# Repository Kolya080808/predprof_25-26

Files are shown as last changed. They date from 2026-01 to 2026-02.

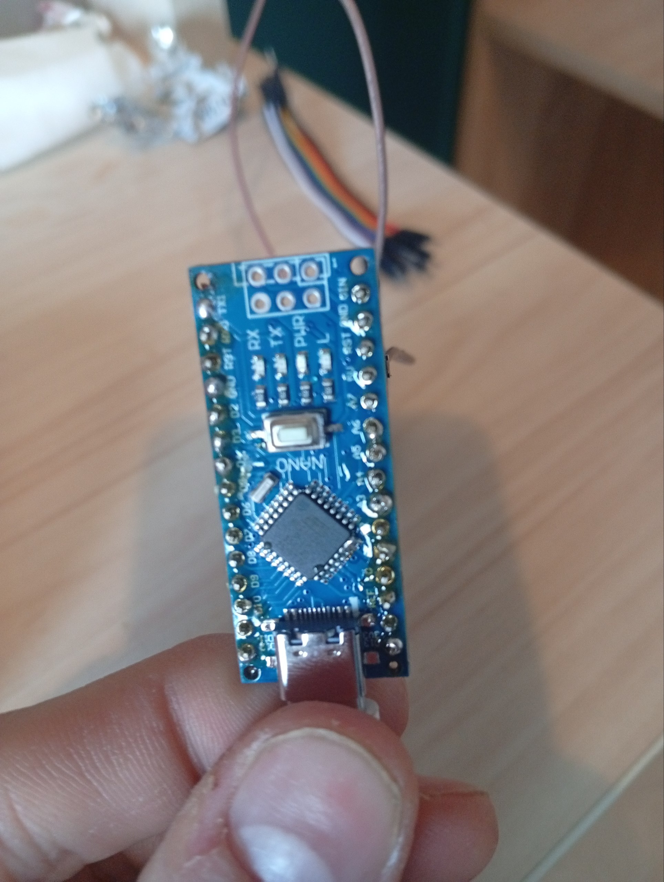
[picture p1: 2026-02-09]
ФотографииСкриншоты/Arduino Nano (transmitter).jpg

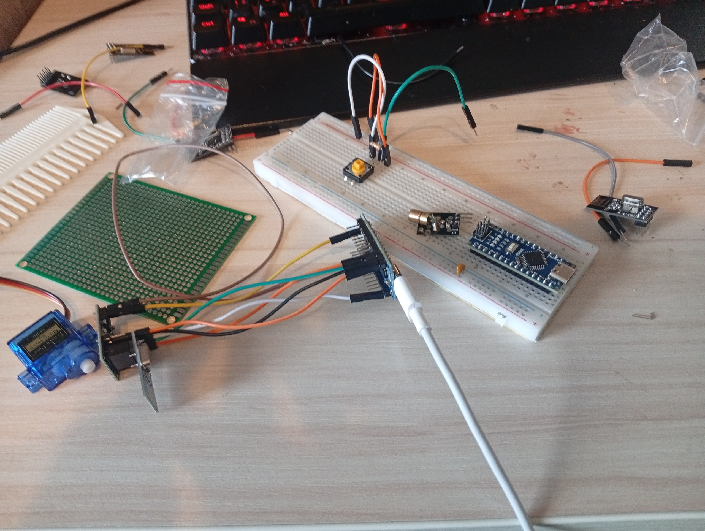
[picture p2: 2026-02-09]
ФотографииСкриншоты/Все комплектующие.jpg

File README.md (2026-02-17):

# predprof_25-26

Команда: `Шестерня и Воля`

- Код передатчика: https://github.com/Kolya080808/predprof_25-26/raw/main/%D0%9F%D1%80%D0%BE%D0%B3%D1%80%D0%B0%D0%BC%D0%BC%D0%BD%D1%8B%D0%B9%20%D0%BA%D0%BE%D0%B4/transmitter.ino
- Код приемника: https://github.com/Kolya080808/predprof_25-26/raw/main/%D0%9F%D1%80%D0%BE%D0%B3%D1%80%D0%B0%D0%BC%D0%BC%D0%BD%D1%8B%D0%B9%20%D0%BA%D0%BE%D0%B4/receiver.ino

## Схемы

- Приемник (CubeSat):



- Передатчик:



## Ссылки

- Документация: https://cloud.predprof.olimpiada.ru/index.php/s/YzEzw9Se8cmYfWE **или** https://github.com/Kolya080808/predprof_25-26/blob/main/%D1%82%D0%B7.pdf 
- Отчет: https://github.com/Kolya080808/predprof_25-26/blob/main/%D0%9E%D0%A2%D0%A7%D0%95%D0%A2%20%D0%9F%D0%A0%D0%95%D0%94%D0%9F%D0%A0%D0%9E%D0%A4.pdf
- Ролик: https://rutube.ru/video/private/c03d32e5083e5afc0b8255f1b30c7123/?p=oxefNFDY0Pq9hNCoUt_76A

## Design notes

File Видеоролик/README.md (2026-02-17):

# ССЫЛКИ НА ВИДЕОРОЛИКИ (скачивание и просмотр)

https://rutube.ru/video/private/c03d32e5083e5afc0b8255f1b30c7123/?p=oxefNFDY0Pq9hNCoUt_76A

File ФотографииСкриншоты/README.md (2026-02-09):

Фотографии разработанного устройства и составных частей, а также скриншоты моделей.

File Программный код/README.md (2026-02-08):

# ССЫЛКИ НА КОД ДЛЯ ПРИЕМНИКА И ПЕРЕДАТЧИКА
- Приемник (CubeSat): https://github.com/Kolya080808/predprof_25-26/blob/main/%D0%9F%D1%80%D0%BE%D0%B3%D1%80%D0%B0%D0%BC%D0%BC%D0%BD%D1%8B%D0%B9%20%D0%BA%D0%BE%D0%B4/receiver.ino

Алгоритм работы:

1. Задает переменные и настройки:
   - Подключает библиотеки для радио и моторов.
   - Назначает пины: 2 (лазер), 3 и 5 (сервомоторы).
   - Задает адреса для радиосвязи («CMD01» для приема, «DATA1» для отправки).
   - Создает структуру TelemetryPacket — «коробку», в которую будут упаковываться данные для отправки.

2. Создает вспомогательные функции:
   - setPosition — управляет сразу двумя моторами (наклоном и поворотом).
   - sendTelemetry — упаковывает текущие углы и режим в пакет и отправляет его по радио.
   - performStep — делает один шаг: сдвинуть моторы -> отправить отчет -> подождать 3 секунды.
   - runScanSequence — содержит сценарий движений: набор циклов для прохода по горизонтали, вертикали и двум диагоналям.

3. Настраивает устройство (setup):
   - Включает лазер (он горит постоянно).
   - Подключает моторы и ставит их в центр.
   - Запускает радиомодуль на прослушивание команд.

4. Слушает эфир (loop):
   - Постоянно проверяет, пришло ли сообщение по радио.
   - Читает сообщение в переменную messange.

5. Выполняет команду:
   - Если пришло слово "start" И программа еще не запущена:
     1. Включает блокировку (isRunning = true).
     2. Запускает функцию runScanSequence (моторы начинают выполнять 4 вида движений по очереди, отправляя отчеты).
     3. После завершения всех движений снимает блокировку и снова ждет команду.

- Передатчик (Пульт): https://github.com/Kolya080808/predprof_25-26/blob/main/%D0%9F%D1%80%D0%BE%D0%B3%D1%80%D0%B0%D0%BC%D0%BC%D0%BD%D1%8B%D0%B9%20%D0%BA%D0%BE%D0%B4/transmitter.ino

Алгоритм работы:

1. Задает переменные и настройки:
   - Подключает библиотеки SPI и RF24.
   - Назначает пины: 9 и 10 (для радио), 2 (для кнопки).
   - Задает адреса: «CMD01» (куда отправлять команды) и «DATA1» (откуда принимать данные).
   - Создает переменные для обработки нажатия кнопки (антидребезг).
   - Создает структуру TelemetryPacket — «коробку», в которую будут приниматься данные от модуля.

2. Настраивает устройство (setup):
   - Запускает Serial-порт для вывода информации на компьютер.
   - Настраивает пин кнопки как вход.
   - Запускает радиомодуль, ставит низкую мощность и скорость 1 Мбит/с.
   - Открывает каналы связи и сразу начинает слушать эфир.

3. Проверяет кнопку (в цикле loop):
   - Считывает состояние кнопки.
   - Если кнопка нажата И состояние изменилось (была не нажата):
     1. Проверяет время для защиты от ложных срабатываний (антидребезг).
     2. Останавливает прослушивание эфира (переходит в режим передачи).
     3. Отправляет команду "start" роботу.
     4. Если отправка не удалась, пишет ошибку в монитор порта.
     5. Снова включает режим прослушивания эфира.

4. Принимает данные (в цикле loop):
   - Проверяет, пришло ли что-то по радио.
   - Если данные есть:
     1. Читает их в структуру TelemetryPacket.
     2. Выводит полученные параметры (ID, режим, углы наклона и поворота) в монитор порта компьютера.

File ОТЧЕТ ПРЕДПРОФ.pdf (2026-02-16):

ГБОУ школа №1205 “Диалог”

МОСКОВСКАЯ | ПРЕДПРОФЕССИОНАЛЬНАЯ
ОЛИМПИАДА | ШКОЛЬНИКОВ
Профиль | | | | | “Инженерия”
Командный | кейс | No1 | "Модуль | системы | наведения”

Команда “Шестерня и Воля”:

Киселев Степан Евгеньевич (капитан)

Кравцов Михаил Дмитриевич

Кравцов Николай Дмитриевич

Шагалов Григорий Михайлович

Юмашев | Захар | Андреевич
Руководитель: | Бурдина | Анастасия | Сергеевна

Цель | | | | | | работы

Главная цель проекта - создание независимого модуля спутника форм фактора

cubesat, | в | соответствии | с | ТЗ | выбранного | кейса.

Задачи:

Разработка и создание 3d модели модуля, с учетом разработанных подвижных

элементов.

1. Выбор и покупка материалов для выполнения.
2. Разработка и создание конструкции модуля
3. Разработка и создание ПО продукта, программирование.
4. Печать созданной 3d модели.
5. Сборка модуля.
6. Испытания и проверка работы.
7. Запись демонстрации.
8. Заключение.

Общее описание функций разработанного решения

Разработанное устройство представляет собой автоматизированный модуль

наведения (турель), управляемый дистанционно. Система функционирует по

принципу «Ведущий-Ведомый» (Transmitter-Receiver).

Основные функции системы:

1. Дистанционный запуск: Активация режима сканирования производится

по радиоканалу (nRF24l01) при нажатии кнопки на пульте управления

(Transmitter).

2. Двухосевое позиционирование: Устройство управляет положением

лазерного целеуказателя в двух плоскостях: горизонтальной и

вертикальной, с помощью сервоприводов.

3. Автоматическое сканирование: Реализован алгоритм последовательного

прохода по заданным траекториям:

- Горизонтальное сканирование (от -40° до +40°).
- Вертикальное сканирование (от -40° до +40°).
- Диагональное сканирование (основная диагональ).
- Диагональное сканирование (побочная диагональ).

Шаг сканирования составляет 10°, задержка фиксации позиции — 3

секунды.

4. Обратная связь (Телеметрия): В процессе работы модуль в реальном

времени отправляет на пульт управления пакеты данных, содержащие:

ID устройства, текущий режим работы (IDLE, HOR, VER, DIAG1,

DIAG2), текущие углы отклонения (Pitch, Yaw).

Описание используемых аппаратных и программных узлов

Аппаратная часть:

Для реализации проекта были выбраны следующие компоненты:

1. Приемник (CubeSat 1U):
a. Микроконтроллерная платформа: Arduino Nano V3.0 - “мозг”

системы, обеспечивающий логику управления и обработку

сигналов.

b. Радиомодуль: nRF24l01 - используется для беспроводной связи

между пультом и модулем наведения на частоте 2.4 Гц.

c. Поворотный механизм: 2 сервопривода SG-90 - исполнительный

элемент системы. С помощью сервоприводов есть возможность

задавать градусную меру, на которую поворачивается лазер.

d. Лазерный модуль: KY-008 - целеуказатель, имитатор полезной

нагрузки.

e. Элемент аварийной остановки: переключатель - если произойдет

внештатная ситуация, есть возможность разорвать цепь путем

перемещения положения переключателя с “ON” на “OFF”.

f. Питание: батарейный блок 4.8V - обеспечивает стабильную

работу системы.

2. Передатчик:
a. Микроконтроллерная платформа: Arduino Uno Piranha - “мозг”

системы передатчика, обеспечивающий обработку полученной

телеметрии и отправку сигнала “START”.

b. Радиомодуль: nRF24l01 - используется для беспроводной связи

между модулем наведения и пультом на частоте 2.4 Гц.

c. Кнопка - исполнительный элемент передатчика. Используется для

отправки сигнала “START”.

Программная часть:

Для реализации проекта были выбраны следующие инструменты и

фреймворки:

1. Среда разработки: Arduino IDE 2.3.7 (C++)
2. Библиотеки:
a. SPI.h - для взаимодействия с радиомодулем по протоколу SPI.
b. RF24.h | — | высокоуровневая | библиотека | для | управления

трансивером nRF24l01.

c. Servo.h — библиотека для генерации ШИМ-сигналов управления

сервоприводами.

Описание | кинематической | системы

Каркас CubeSat, размером 100 на 100 на 100 мм с направляющими рельсами

113.5 на 8.5 на 8.5 мм c креплениями для стенок, электроники и гироскопа;

гироскопическое крепление, позволяет закрепить сервопривод для движения

по двум осям, размером 38.2 на 19 на 28 мм; верхняя стенка (x2), размером 93.6

на 93.6 на 3;, боковая стенка (x2), размером 99,6 на 82,6 на 3 мм, задняя стенка,

размером 99.6 на 82.6 на 19.8.

На каркас заклепками крепятся все детали для устойчивого соединения.

Сервопривод плотно вставляется в отверстие, фиксируя свое положение в

центре по осям x и y. Сверху к сервоприводу присоединяется гироскопическое

крепление, которое удерживает второй сервопривод. Второй сервопривод

также плотно вставляется в отверстие в креплении, находясь ровно в центре

Cubesat и позволяя выполнять движения в плоскостях xy и xz. Крепление

электроники осуществляется четырьмя опорами над гироскопическим

механизмом.

Все движения являются вращательными и равномерными, движение

происходит в плоскости xy за счет первого сервопривода и в плоскости xz с

помощью второго сервопривода.

С моделями, чертежами составных частей кинематической системы можно

ознакомиться по ссылкам:

1. Скриншоты | моделей: | https://github.com/Kolya080808/predprof_25-

26/tree/main/%D0%A4%D0%BE%D1%82%D0%BE%D0%B3%D1%80%

D0%B0%D1%84%D0%B8%D0%B8%D0%A1%D0%BA%D1%80%D0%

B8%D0%BD%D1%88%D0%BE%D1%82%D1%8B (https://github.com/Kolya080808/predprof_25-26/tree/main/%D0%A4%D0%BE%D1%82%D0%BE%D0%B3%D1%80%D0%B0%D1%84%D0%B8%D0%B8%D0%A1%D0%BA%D1%80%D0%B8%D0%BD%D1%88%D0%BE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)

2. Модели | и | чертежи: | https://github.com/Kolya080808/predprof_25-

26/tree/main/3D-

%D0%BC%D0%BE%D0%B4%D0%B5%D0%BB%D0%B8 (https://github.com/Kolya080808/predprof_25-26/tree/main/3D-%D0%BC%D0%BE%D0%B4%D0%B5%D0%BB%D0%B8)

Описание электротехнической схемы

1. Приемник (CubeSat 1U):

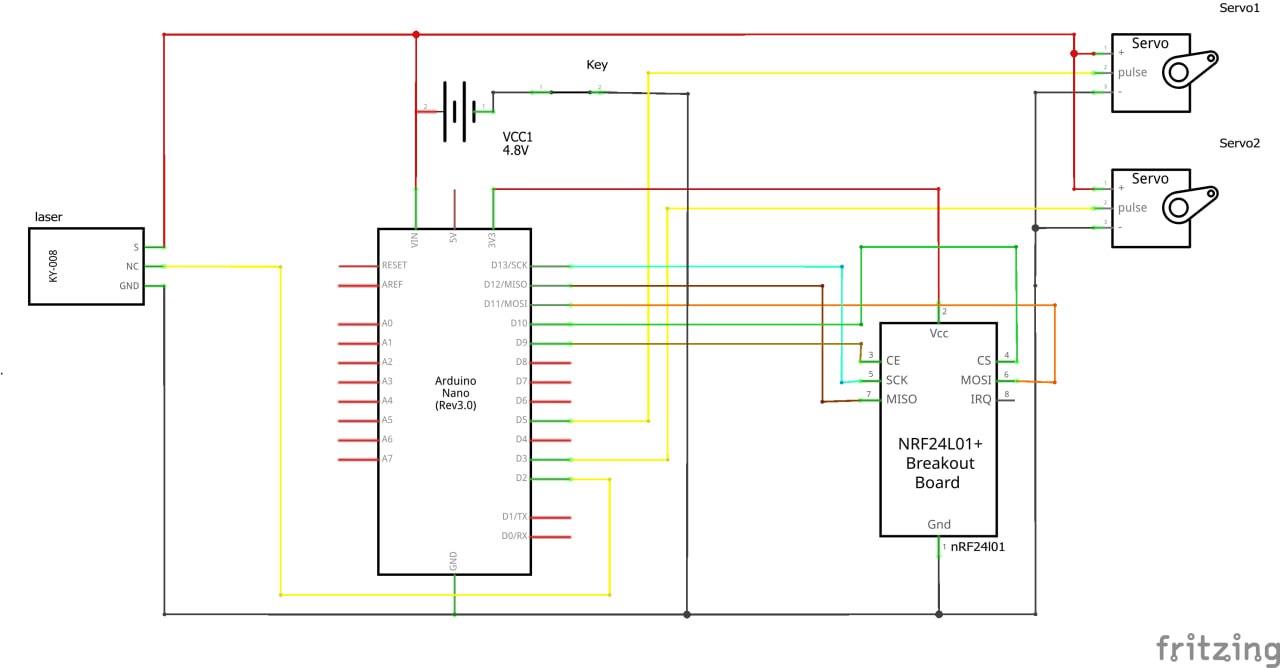
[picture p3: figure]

Основой схемы модуля наведения является микроконтроллер Arduino Nano,

обеспечивающий управление периферией и обработку данных.

Исполнительные механизмы:

- Два сервопривода SG-90 подключены к цифровым выводам с

поддержкой ШИМ (PWM): Ось Yaw (горизонталь) — к пину D3, Ось

Pitch (вертикаль) — к пину D5.

- Лазерный модуль KY-008 (имитатор полезной нагрузки) подключен к

цифровому выводу D2. Управление осуществляется логическим

уровнем (HIGH/LOW).

Связь:

Радиомодуль nRF24L01+ подключен по интерфейсу SPI (MOSI, MISO, SCK).

Линии управления CE и CSN выведены на пины D9 и D10 соответственно.

Питание (Power):

- Основное питание системы осуществляется от аккумуляторной сборки

напряжением 4.8 В, подключенной к входу питания микроконтроллера.

- Питание радиомодуля nRF24L01 (3.3 В) берется со встроенного

стабилизатора Arduino Nano для защиты чувствительной электроники.

- В цепь питания интегрирован аварийный аппаратный размыкатель,

позволяющий мгновенно обесточить устройство в случае нештатной

ситуации.

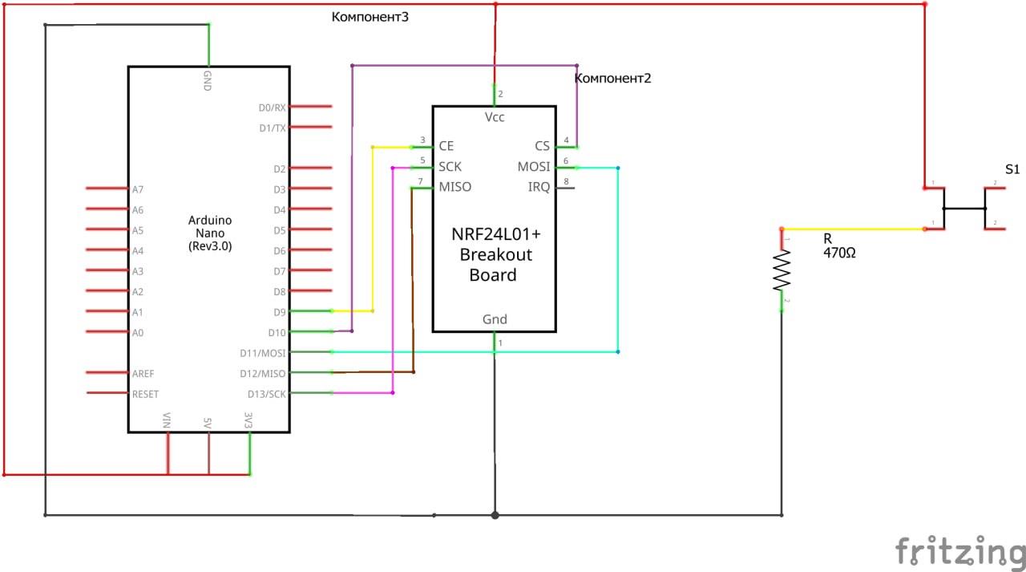
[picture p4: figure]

Схема передатчика реализована на базе платы Arduino Nano.

Органы управления:

Тактовая кнопка запуска подключена к цифровому входу D2. Реализована

программная подтяжка (или внешняя, согласно схеме) для фиксации

логических уровней.

Связь и мониторинг:

- Подключение | радиомодуля | nRF24L01+ | аналогично | приемнику:

интерфейс SPI, линии управления CE/CSN на пинах D9 и D10.

- Для вывода телеметрии используется интерфейс UART (USB-

соединение с ПК), через который данные передаются в Serial Monitor

(9600 бод).

Питание:

Питание пульта осуществляется от USB-порта ПК. Радиомодуль запитан от

линии 3.3 В платы Arduino Nano.

Алгоритм работы

Модуль наведения (CubeSat 1U):

Логика работы: Программа ожидает управляющую команду, после чего

запускает жестко заданную последовательность действий (State Machine),

блокируя прием новых команд до завершения маневра.

1. Инициализация (Setup):
a. Активация лазерного модуля (Pin 2 HIGH).
b. Установка сервоприводов в начальное положение (90°, 90°).
c. Настройка радиомодуля на прием данных.
2. Основной цикл (Loop):
a. Ожидание данных из радиоэфира.
b. При получении строки "start" и отсутствии флага блокировки

!isRunning запускается процедура сканирования.

c. Процедура сканирования (runScanSequence):
d. Выполняется последовательный перебор координат для 4-х

режимов (Горизонталь, Вертикаль, Диагональ 1, Диагональ 2).

e. В каждом шаге вызывается подфункция performStep, которая:
f. Поворачивает сервоприводы.
g. Формирует пакет телеметрии.
h. Переключает радиомодуль на передачу, отправляет пакет,

возвращает на прием.

i. Выполняет задержку 3000 мс.

Блок-схема:

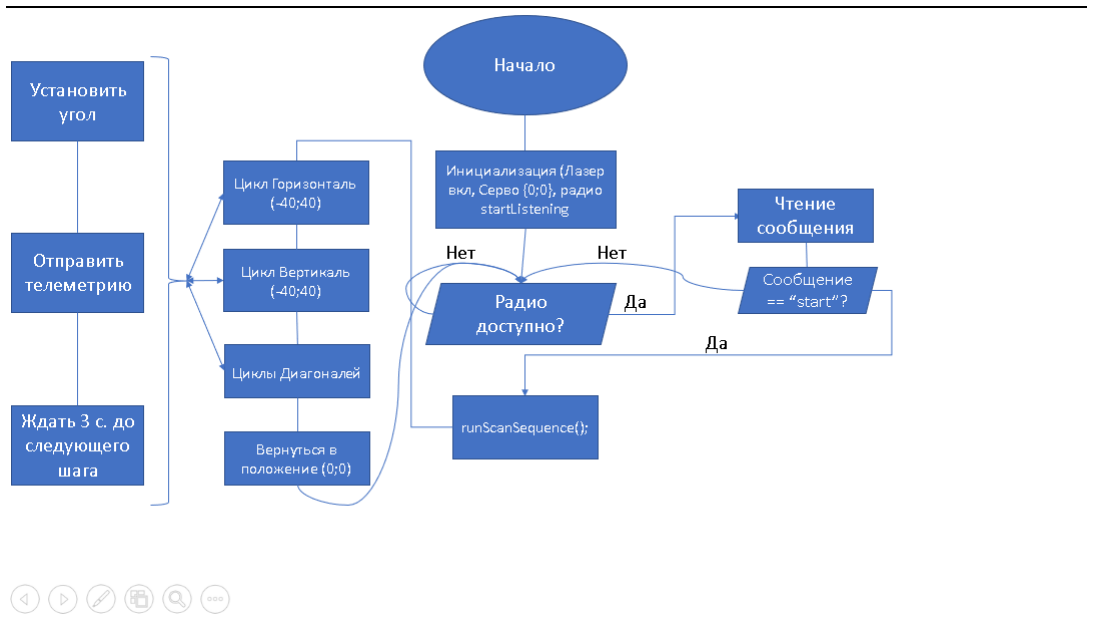
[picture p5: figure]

Передатчик:

Логика работы: Программа работает в цикличном режиме опроса состояния

кнопки и проверки радиоэфира.

Инициализация (Setup):

- Настройка портов ввода-вывода (кнопка — вход, радиомодуль — шина

SPI).

- Установка параметров радиообмена: канал, мощность (Low), скорость

(1 Мбит/с).

- Открытие каналов: writingPipe (передача команд) и readingPipe (прием

телеметрии).

Основной цикл (Loop):

- Блок | управления: | считывается | состояние | кнопки. | Реализован

программный алгоритм подавления дребезга контактов (Debounce) с

задержкой 50 мс. При фиксации нажатия радиомодуль переводится в

режим передатчика, отправляет пакет данных char messange[] = "start" и

возвращается в режим приема.

- Блок телеметрии: Проверяется буфер радиомодуля. При наличии

входящих данных они десериализуются в структуру TelemetryPacket.

Данные (ID, режим, углы Pitch/Yaw) выводятся в Serial-порт для отладки

и мониторинга.

Блок-схема:

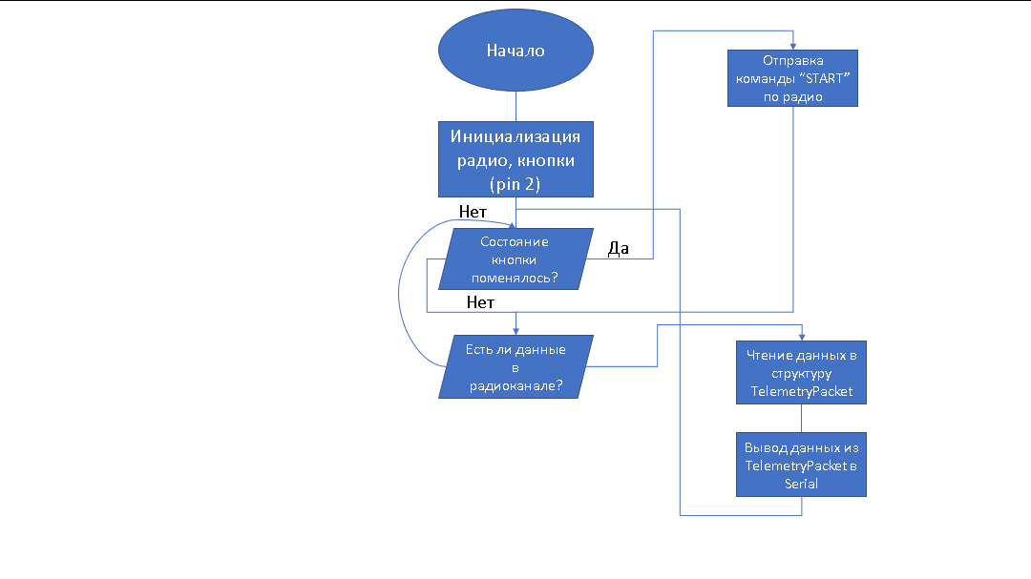
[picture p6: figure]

Ознакомиться с кодом можно по следующим ссылкам:

1. Код | приемника | (модуля) | (CubeSat | 1U):

https://github.com/Kolya080808/predprof_25-

26/blob/main/%D0%9F%D1%80%D0%BE%D0%B3%D1%80%D0%B0%

D0%BC%D0%BC%D0%BD%D1%8B%D0%B9%20%D0%BA%D0%BE

%D0%B4/receiver.ino (https://github.com/Kolya080808/predprof_25-26/blob/main/%D0%9F%D1%80%D0%BE%D0%B3%D1%80%D0%B0%D0%BC%D0%BC%D0%BD%D1%8B%D0%B9%20%D0%BA%D0%BE%D0%B4/receiver.ino)

2. Код | передатчика | (пульта | и | приемника | телеметрии):

https://github.com/Kolya080808/predprof_25-

26/blob/main/%D0%9F%D1%80%D0%BE%D0%B3%D1%80%D0%B0%

D0%BC%D0%BC%D0%BD%D1%8B%D0%B9%20%D0%BA%D0%BE

%D0%B4/transmitter.ino (https://github.com/Kolya080808/predprof_25-26/blob/main/%D0%9F%D1%80%D0%BE%D0%B3%D1%80%D0%B0%D0%BC%D0%BC%D0%BD%D1%8B%D0%B9%20%D0%BA%D0%BE%D0%B4/transmitter.ino)

Заключение

В ходе выполнения работы был разработан и прототипирован модуль системы

наведения формата CubeSat 1U.

Результаты:

- Создана 3D-модель и распечатан корпус устройства.
- Разработана | электрическая | схема, | объединяющая | радиоканал,

сервоприводы и лазерную индикацию.

- Написано программное обеспечение, реализующее сложный алгоритм

сканирования пространства по 4 траекториям.

- Реализован протокол двусторонней связи: прием команд управления и

передача телеметрии.

Анализ функционирования показал стабильную работу на дистанции

уверенного приема NRF24L01. Точность позиционирования соответствует

техническим характеристикам используемых сервоприводов.

Предложения по улучшению:

1. Замена сервоприводов на модели с металлическим редуктором для

повышения точности и надежности.

2. Использование более мощного радиомодуля (NRF24L01+PA+LNA) для

увеличения дальности связи.

3. Отправка сигналов позиционирования - так будет возможность

наводится по сигналам с земли, например, на определенный город.

4. Внедрение ПИД-регулятора для плавности хода.

Источники

1. Optimized high speed nRF24L01+ driver class documentation -

https://nrf24.github.io/RF24/

2. Российский форум Arduino - https://arduino.ru/forum
3. Fritzing User Manual - https://fritzing.org/learning/full_reference
4. Техническое задание. Командный кейс № 1 "Модуль системы
наведения" | | | -

https://cloud.predprof.olimpiada.ru/index.php/s/YzEzw9Se8cmYfWE

Ссылки

1. Репозиторий | проекта | на | GitHub:

https://github.com/Kolya080808/predprof_25-26

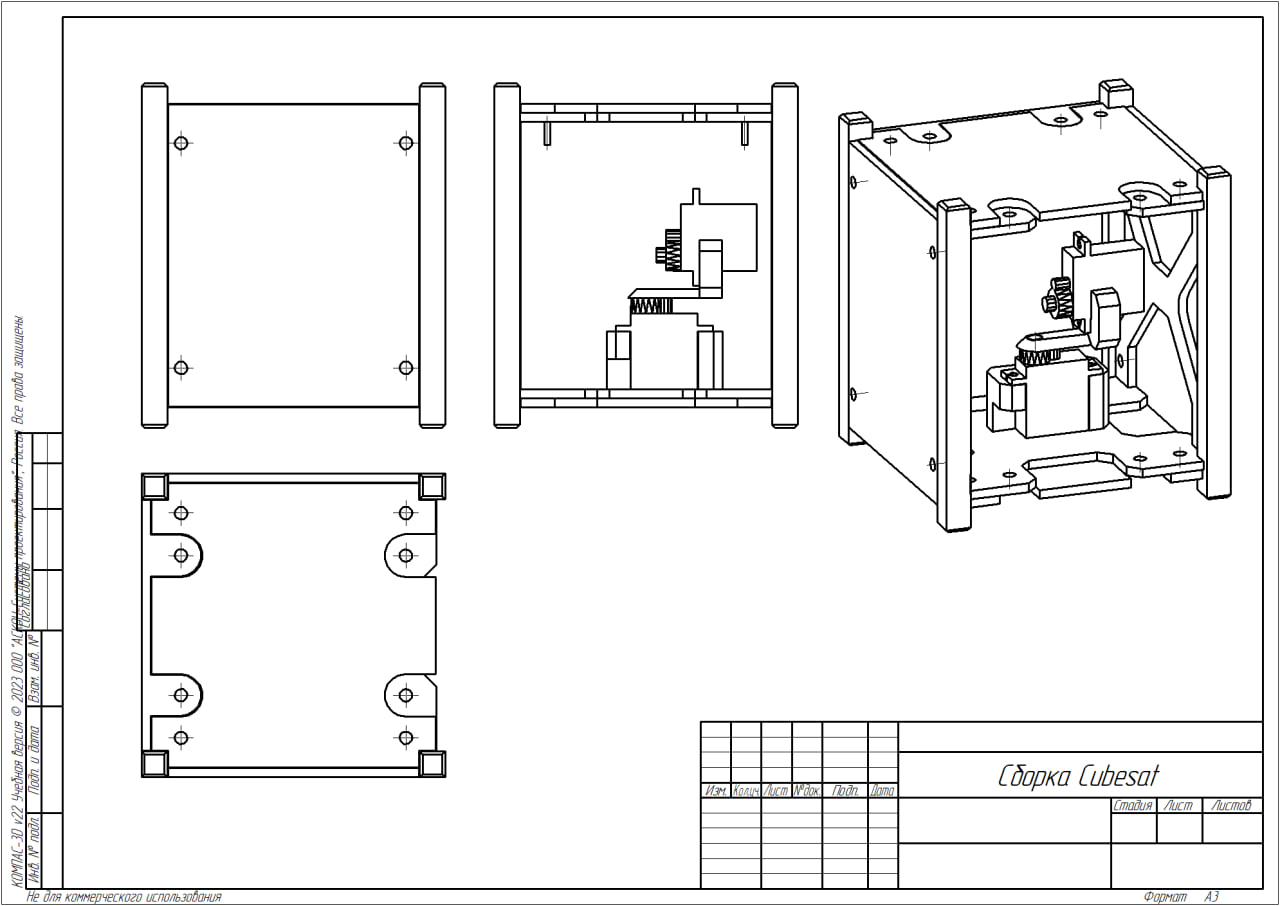
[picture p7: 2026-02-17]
3D-модели/сборка чертеж.jpg

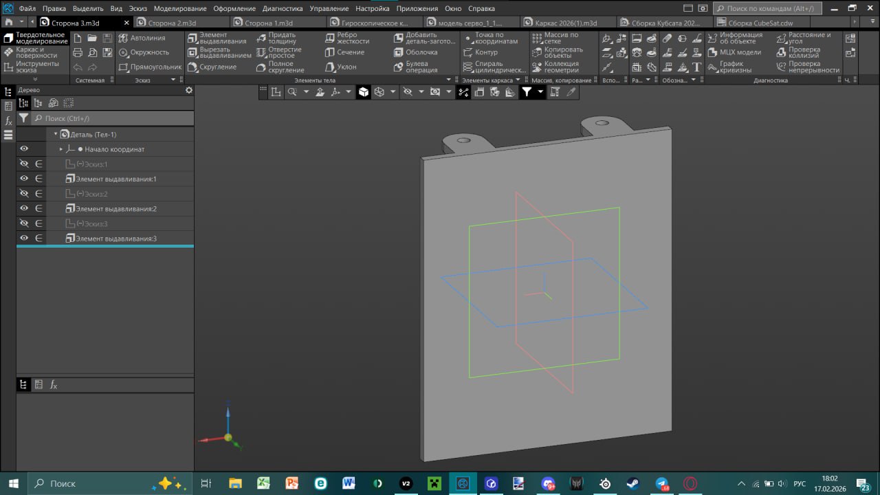
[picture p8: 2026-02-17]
3D-модели/сторона 3 скрин.jpg

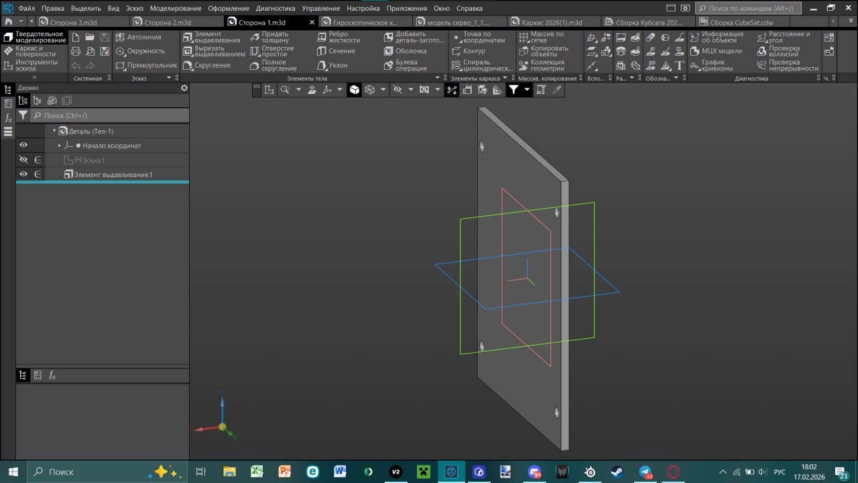
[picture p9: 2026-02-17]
3D-модели/сторона 1 скрин.jpg

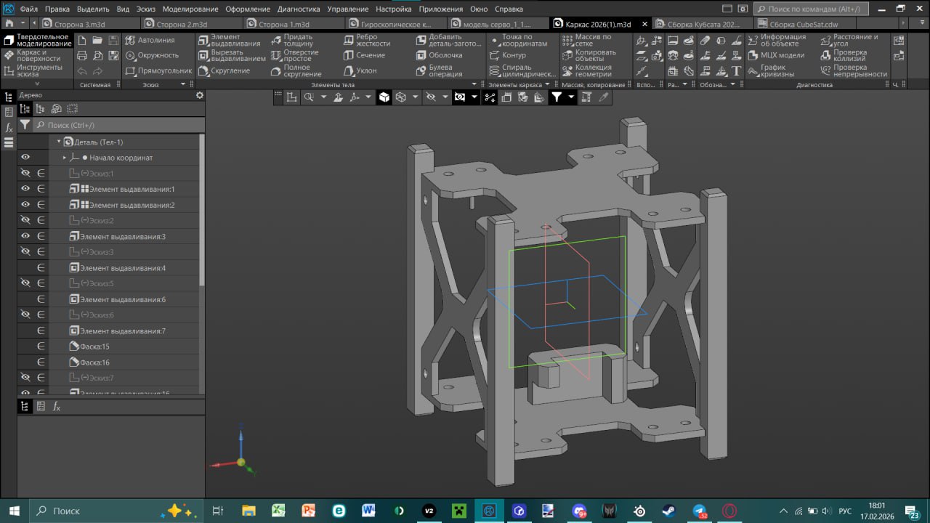
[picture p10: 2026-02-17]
3D-модели/корпус скрин.jpg

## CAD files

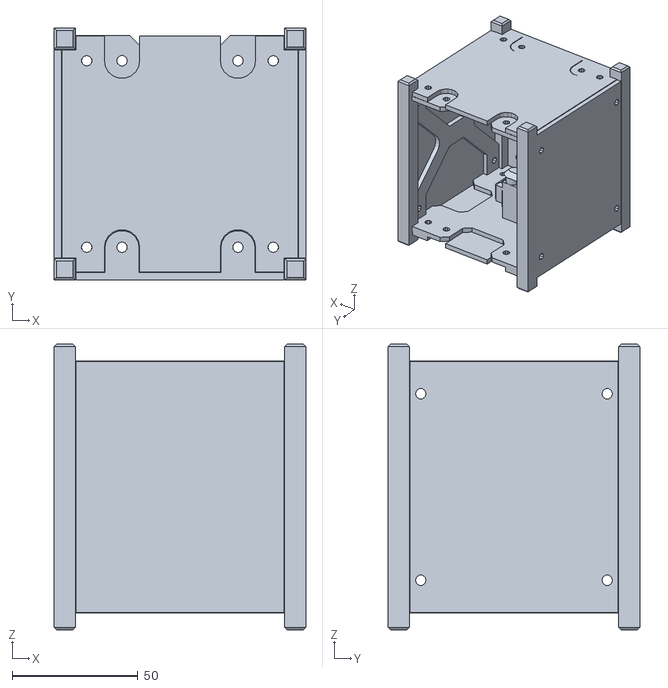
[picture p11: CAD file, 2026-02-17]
3D-модели/Сборка Кубсата 2026.stl
100.0 x 100.0 x 113.5

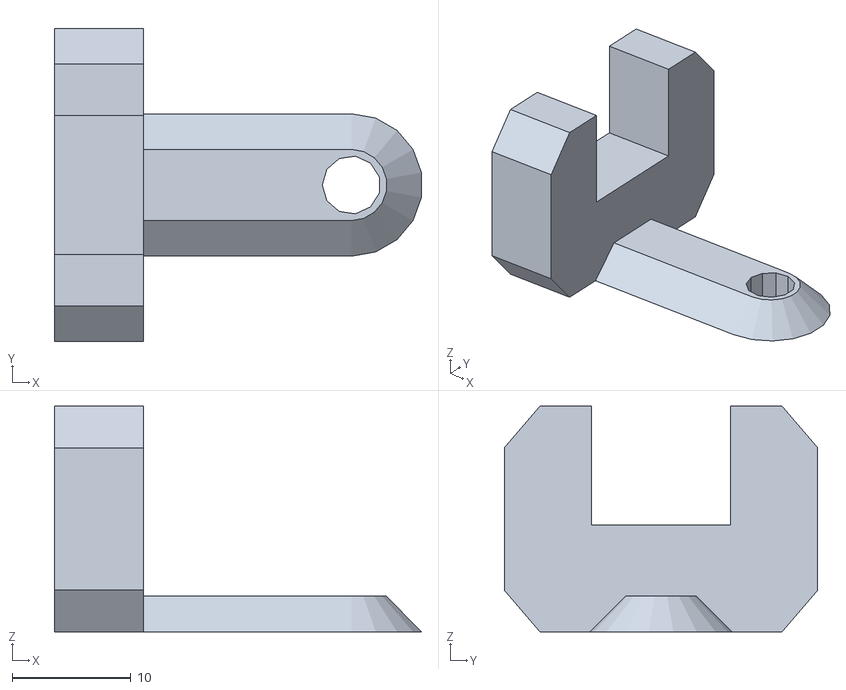
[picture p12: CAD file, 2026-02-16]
3D-модели/Гироскопическое крепление(1).stl
30.9 x 26.4 x 19.0

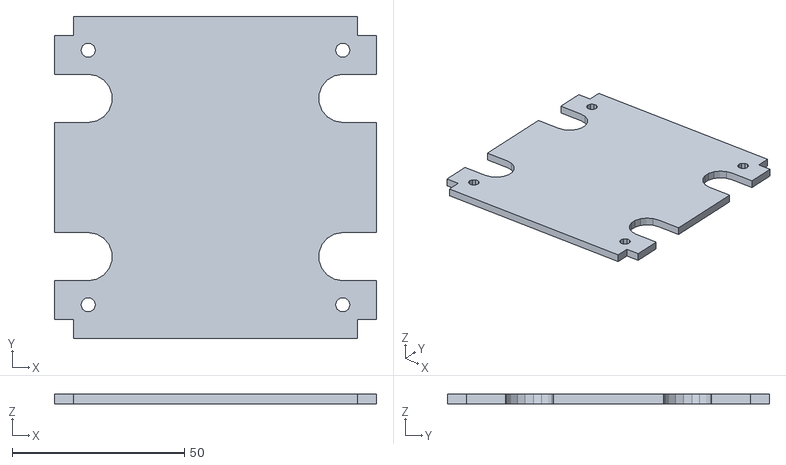
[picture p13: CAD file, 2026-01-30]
3D-модели/Сторона 2.stl
93.6 x 93.6 x 3.00

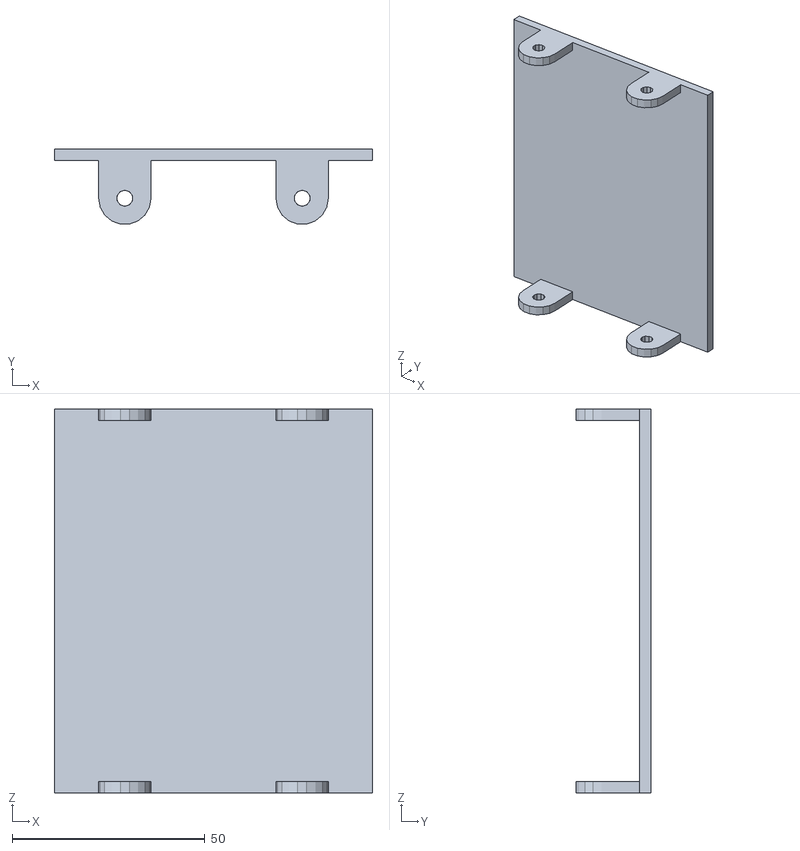
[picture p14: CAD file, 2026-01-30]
3D-модели/Сторона 3.stl
82.6 x 19.5 x 99.6

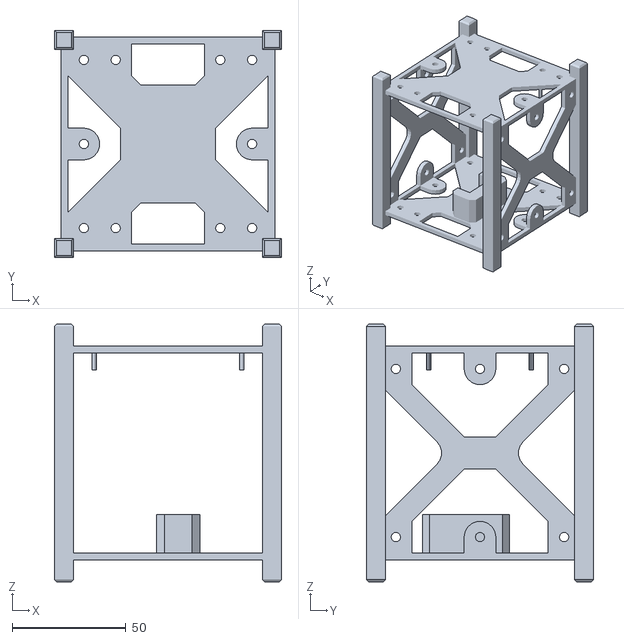
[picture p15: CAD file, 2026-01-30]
3D-модели/Каркас 2026.stl
100.0 x 100.0 x 113.5

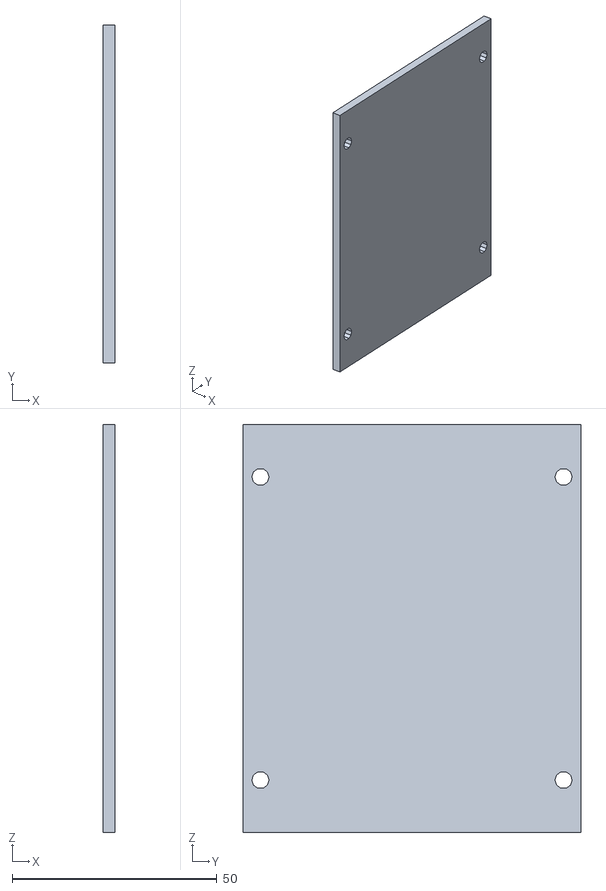
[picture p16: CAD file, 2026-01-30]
3D-модели/Сторона 1.stl
3.00 x 82.6 x 99.6

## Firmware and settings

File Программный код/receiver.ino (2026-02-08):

#include <SPI.h>
#include <RF24.h>
#include <Servo.h>

const uint8_t laserPin = 2;
const uint8_t servoPinH = 3;
const uint8_t servoPinV = 5;
const uint8_t startAngle = 90;

RF24 radio(9, 10);
const byte addressRx[] = "CMD01";
const byte addressTx[] = "DATA1";

char messange[8];

struct TelemetryPacket {
  char id[4];
  char mode[2];
  char pitch[4];
  char yaw[4];
};

TelemetryPacket telemetry;
Servo servoYaw, servoPitch;

const uint8_t DEVICE_ID = 101;
const int STEP_DELAY = 3000;

bool isRunning = false;

enum Mode {
  MODE_IDLE   = 0,
  MODE_HOR    = 1,
  MODE_VER    = 2,
  MODE_DIAG1  = 3,
  MODE_DIAG2  = 4,
};

uint8_t getServoAngle(int8_t angle) {
  return startAngle + angle;
}
void setPosition(int8_t pitch, int8_t yaw) {
  servoPitch.write(getServoAngle(pitch));
  servoYaw.write(getServoAngle(yaw));
}
void sendTelemetry(int8_t pitch, int8_t yaw, uint8_t mode) {
  itoa(DEVICE_ID,telemetry.id,10);
  itoa(pitch,telemetry.pitch,10);
  itoa(yaw,telemetry.yaw,10);
  itoa(mode,telemetry.mode,10);
  radio.stopListening();
  radio.write(&telemetry, sizeof(telemetry));
  radio.startListening();
  Serial.print("Sent: M="); Serial.print(mode);
  Serial.print(" P="); Serial.print(pitch);
  Serial.print(" Y="); Serial.println(yaw);
}

void performStep(int8_t pitch, int8_t yaw, uint8_t mode) {
  setPosition(pitch, yaw);
  sendTelemetry(pitch, yaw, mode);
  delay(STEP_DELAY);
}

void runScanSequence() {
  for (int8_t p = -40; p <= 40; p += 10) {
    performStep(p, 0, MODE_HOR);
  }
  for (int8_t y = -40; y <= 40; y += 10) {
    performStep(0, y, MODE_VER);
  }
  for (int8_t i = -40; i <= 40; i += 10) {
    performStep(i, i, MODE_DIAG1);
  }
  for (int8_t i = -40; i <= 40; i += 10) {
    performStep(i, -i, MODE_DIAG2);
  }
  setPosition(0, 0);
  sendTelemetry(0, 0, MODE_IDLE);
}

void setup() {
  Serial.begin(9600);
  pinMode(laserPin, OUTPUT);
  digitalWrite(laserPin, HIGH);
  servoYaw.attach(servoPinH);
  servoPitch.attach(servoPinV);
  setPosition(0, 0);
  radio.begin();
  radio.setPALevel(RF24_PA_LOW);
  radio.setDataRate(RF24_1MBPS);
  radio.openReadingPipe(1, addressRx);
  radio.openWritingPipe(addressTx);
  radio.startListening();
}

void loop() {
  if (radio.available()) {
    radio.read(&messange, sizeof(messange));
    if (!isRunning && String(messange) == "start") {
      isRunning = true;
      runScanSequence();
      isRunning = false;
    }
  }
}

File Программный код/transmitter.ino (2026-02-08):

#include <SPI.h>
#include <RF24.h>

RF24 radio(9, 10);
const int buttonPin = 2;

const byte addressTx[] = "CMD01";
const byte addressRx[] = "DATA1";

byte lastbuttonState = 0;
byte nowbuttonstate = 0;
int timetopress = 50;

char messange[] = "start";

struct TelemetryPacket {
  char id[4];
  char mode[2];
  char pitch[4];
  char yaw[4];
};

TelemetryPacket telemetry;

void setup() {
  Serial.begin(9600);
  pinMode(buttonPin, INPUT);
  radio.begin();
  radio.setPALevel(RF24_PA_LOW);
  radio.setDataRate(RF24_1MBPS);
  radio.openWritingPipe(addressTx);
  radio.openReadingPipe(1, addressRx);
  radio.startListening();
}

void loop() {
  nowbuttonstate = digitalRead(buttonPin);
  if(nowbuttonstate && nowbuttonstate != lastbuttonState ){
    if(millis() - timetopress > 50){
      timetopress = millis();
      Serial.println("Button pressed. Sending START.");
      radio.stopListening();
      bool ok = radio.write(&messange, sizeof(messange));
      if (!ok) Serial.println("Ошибка: команда не отправлена!");
      radio.startListening();
    }
  }
  lastbuttonState = nowbuttonstate;

  if (radio.available()) {
    TelemetryPacket newTel;
    radio.read(&newTel, sizeof(newTel));
    Serial.print("RECV | ID: "); Serial.print(newTel.id);
    Serial.print(" | Mode: "); Serial.print(newTel.mode);
    Serial.print(" | Pitch: "); Serial.print(newTel.pitch);
    Serial.print(" | Yaw: "); Serial.println(newTel.yaw);
    
  }
}

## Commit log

2025-12-23 Сделал код для передатчика. Добавил ссылку на него в ридми. Чуть подправил все остальные ридми.
2025-12-23 Добавил небольшую часть отчета по передатчику.
2025-12-24 Добавил ack, чтобы не думать над синхронизацией. Исправил документацию (много повтроений было и т.п.).
    [receiver.ino, transmitter.ino]
2025-12-29 A bit corrected address
    [transmitter.ino]
2025-12-29 Add servo control and field of view checks
2025-12-29 Change pitch and yaw parameters to int8_t in sendPacket
2025-12-29 Обновить README с изменениями в коде приемника и передатчика
    Обновлен код приемника для управления сервоприводами и улучшена логика подтверждения. Также уточнены детали работы передатчика и его функций.
2025-12-29 Add serial print statements for servo and laser initialization
2025-12-29 Clarify button press behavior in loop function
    Updated the description of the loop function to clarify that the data is called after a button press and continues until the button is pressed again.
2025-12-29 Обновить README с деталями о приемнике и передатчике
    Обновлено описание кода приемника и передатчика, добавлено управление сервоприводами и улучшена логика передачи данных.
2026-01-03 Обновлено описание приёмника и передатчика в README
    Добавлено описание приёмника и передатчика, включая детали о микроконтроллерах, радиомодулях и источниках питания.
2026-01-16 Переписан код. Исправлены ошибки в логике. Изменен вид вывода. Изменено описание кода.
    [receiver.ino, transmitter.ino]
2026-01-16 Чуть-чуть исправил код. Переписал описание для электронщика.
    [receiver.ino]
2026-01-25 Исправил логические ошибки
2026-02-08 Update transmitter code for button and telemetry
    Refactored button handling and telemetry structure.
2026-02-08 Обновить README.md с описанием приемника и передатчика
    Обновлен раздел с описанием алгоритмов работы приемника и передатчика, добавлены детали по настройкам и функциям.
2026-02-08 Update receiver and transmitter descriptions in README
    Обновлено описание работы приемника и передатчика, добавлены алгоритмы и детали настройки.
2026-02-09 Add README with device photos and model screenshots
